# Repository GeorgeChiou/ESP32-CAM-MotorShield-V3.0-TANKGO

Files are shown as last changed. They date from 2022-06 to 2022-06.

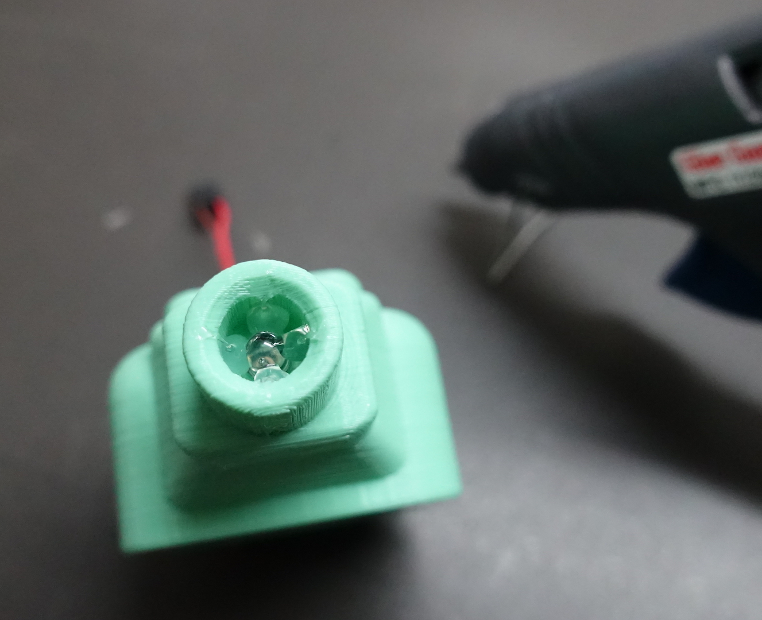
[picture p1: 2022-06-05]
Assembly Instruction/DSC00389.JPG

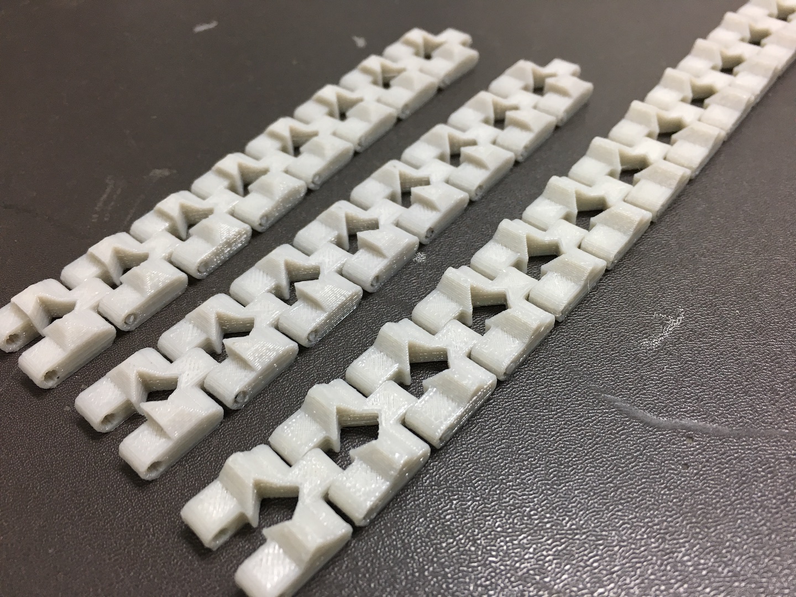
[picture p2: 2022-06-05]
Assembly Instruction/TANK_GO_3.JPG

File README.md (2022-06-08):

Key Features :<br>
Compact all-in-one design<br>
USB for Chargering<br>
Provide 4 GPIO ports to control up to 4 servo motors simultaneously<br>
I2C port for expansion of extra functions<br>
5V / 350mAh Lithium Ion Capacitor for power with nominal output of 10C<br>

Dimension is L55mm x W44mm x H23mm<br>

DC Motor x 2：2.5V ~ 6V , Avg. 1.2A , Max 2.0A<br>
Buzzer x 1 : SW3 ( Buzzer / P2 )<br>
I2C x 1 : ( P3 , P1 , 3.3V , GND )<br>
Ext. x 1 : ( P4 , P2 , VCC , GND )<br>
Upload Program x 1 : ( RX , TX , VCC , GND )

Power Consumption<br>
Idle Mode : 2mA<br>
Active Mode : 2.5A<br>
Operating Voltage : 3.9V ~ 5.1V<br>
Battery Voltage Indication : Red light below 3.9V, Green light above 4.2V<br>

電商販售連結 ICSHOP https://www.icshop.com.tw/product-page.php?28709<br>

LEGO Part :<br>
No.4666579 Axle Pin without Friction x 4pcs<br>
No.55982 Black Wheel 18mm D. x 14mm with Axle Hole x 4pcs<br>
No.43903 Technic Tread (Small) x 2pcs<br>
熱縮套管 heat shrink tube Φ2mm<div>ESP32-CAM Motor Shield - TANK GO ! Build Instruction 程式燒錄與組裝說明</div>
<div></div>

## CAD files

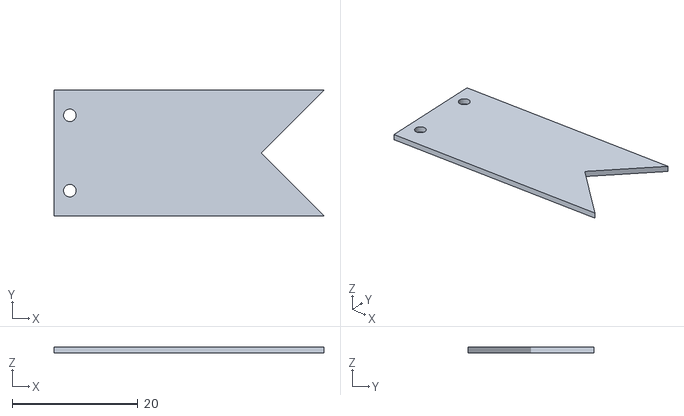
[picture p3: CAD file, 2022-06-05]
3DP STL BattleTower/TANK GO irBattleTower Flag.stl
43.0 x 20.0 x 1.00

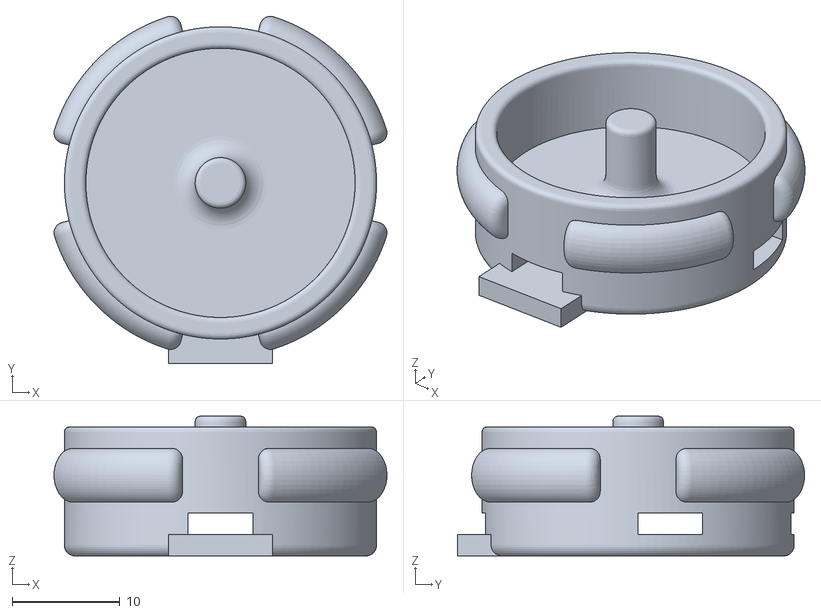
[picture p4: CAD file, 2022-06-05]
3DP STL TANKGO/GoodSmileDoll_IR_Cover.stl
30.9 x 32.3 x 13.0

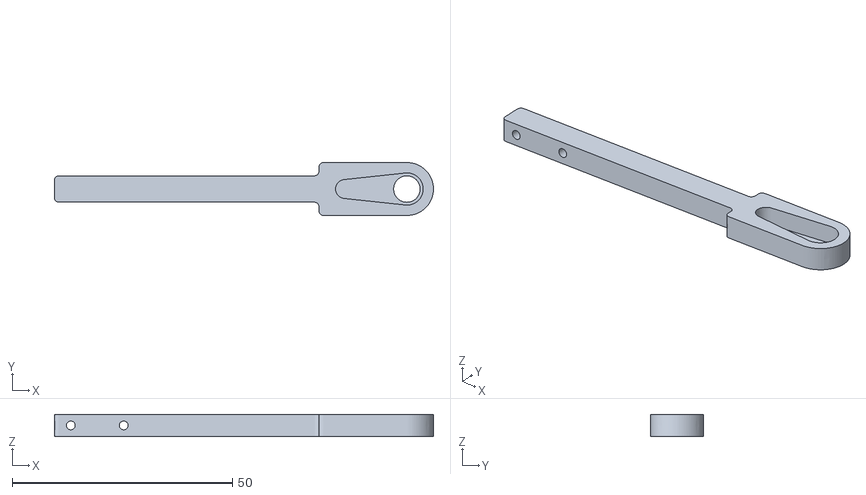
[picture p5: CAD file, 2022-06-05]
3DP STL BattleTower/TANK GO irBattleTower Stick.stl
86.0 x 12.0 x 5.00

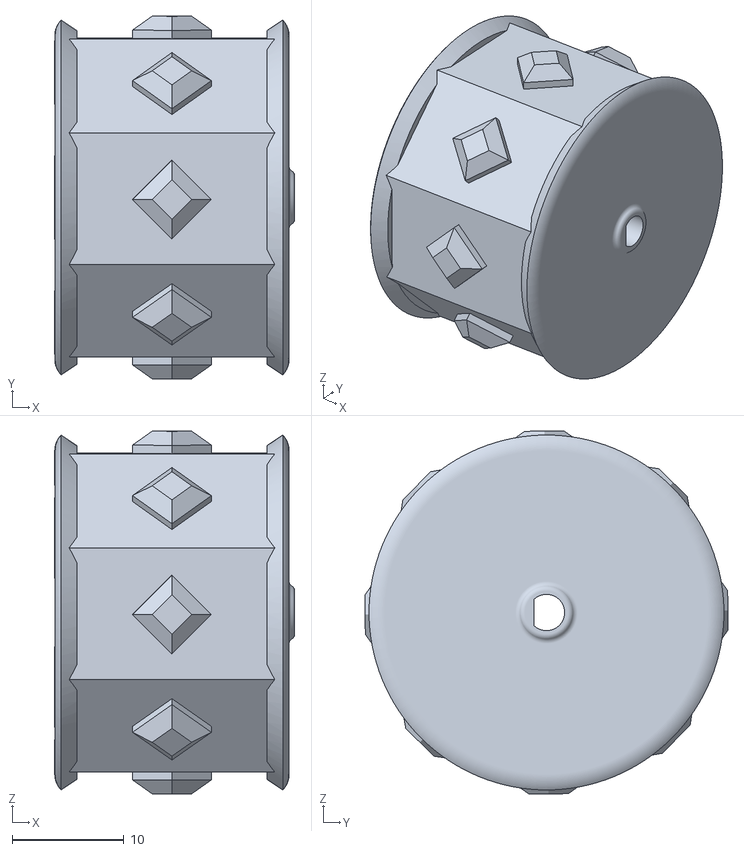
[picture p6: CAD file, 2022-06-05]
3DP STL TANKGO/Wheel_Master_2PCS.stl
21.5 x 32.5 x 32.5

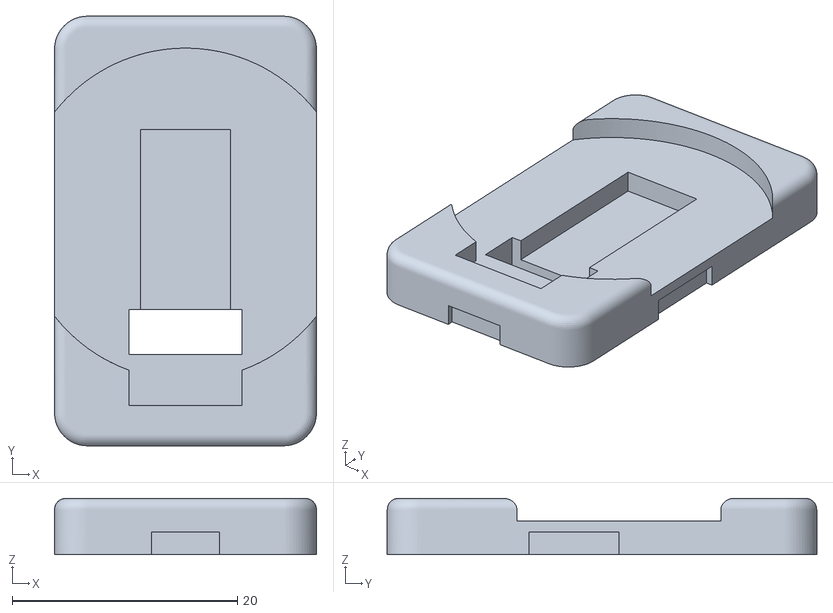
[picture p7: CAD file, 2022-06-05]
3DP STL BattleTower/GoodSmileDoll_Turret_Cover.stl
23.3 x 38.2 x 5.00

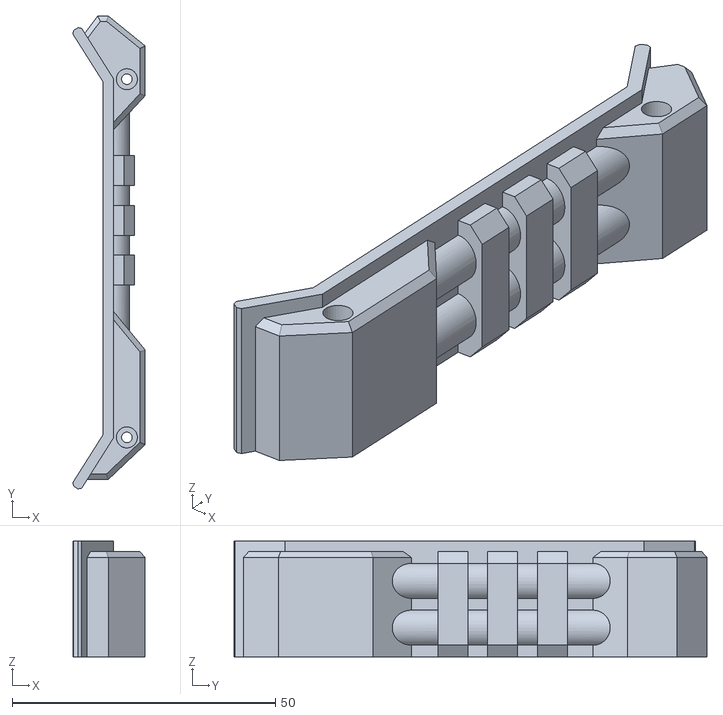
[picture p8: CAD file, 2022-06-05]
3DP STL TANKGO/Wheel_Armor_X_R.stl
13.7 x 89.8 x 22.0

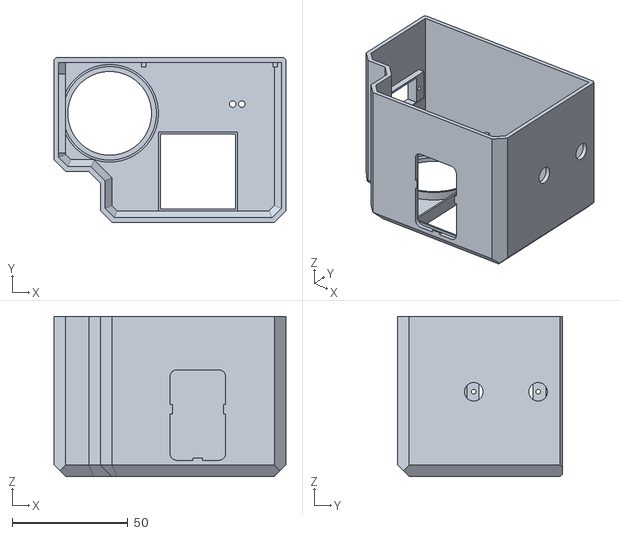
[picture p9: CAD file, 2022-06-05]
3DP STL BattleTower/TANK GO irBattleTower.stl
100.0 x 71.0 x 69.0

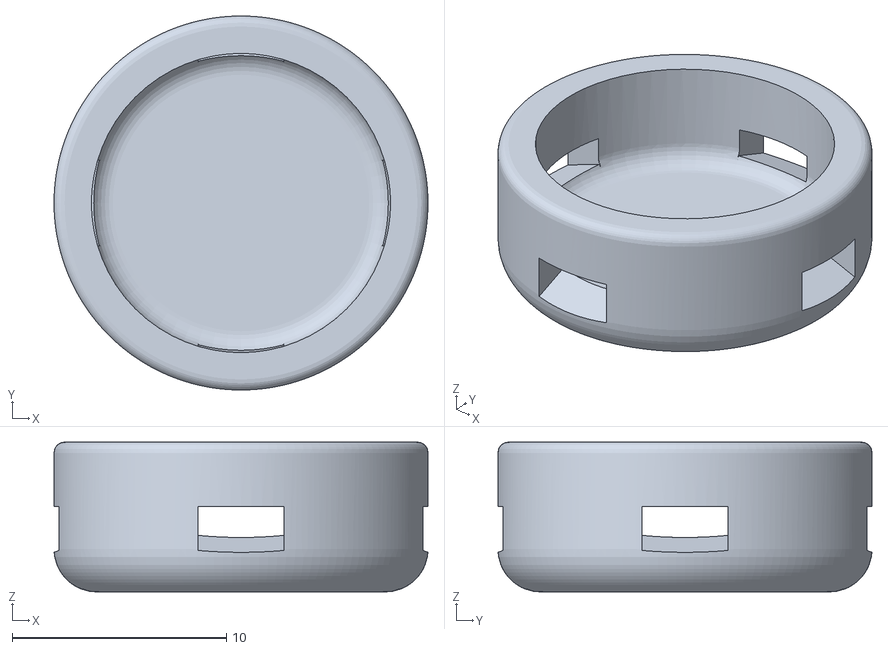
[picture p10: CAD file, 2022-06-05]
3DP STL TANKGO/IR_Cover.stl
17.5 x 17.5 x 7.00

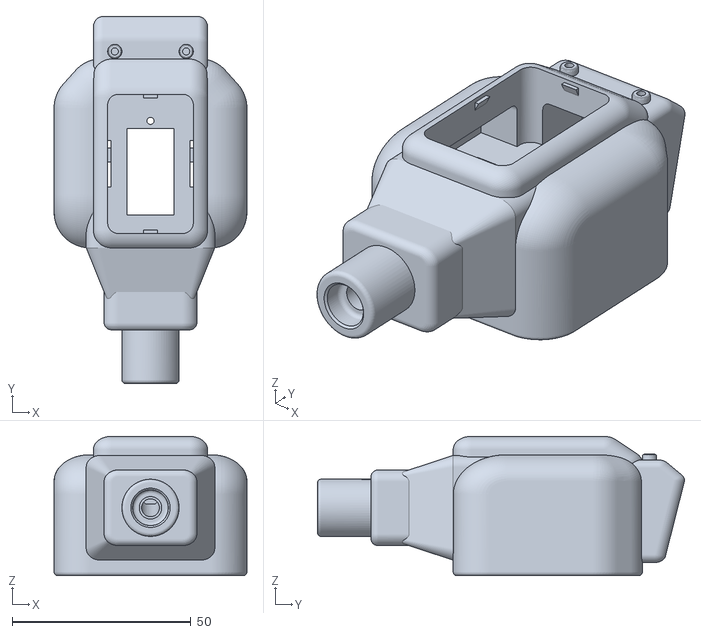
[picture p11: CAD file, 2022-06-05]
3DP STL TANKGO/Turret_MetalSlug.stl
54.0 x 102.8 x 39.0

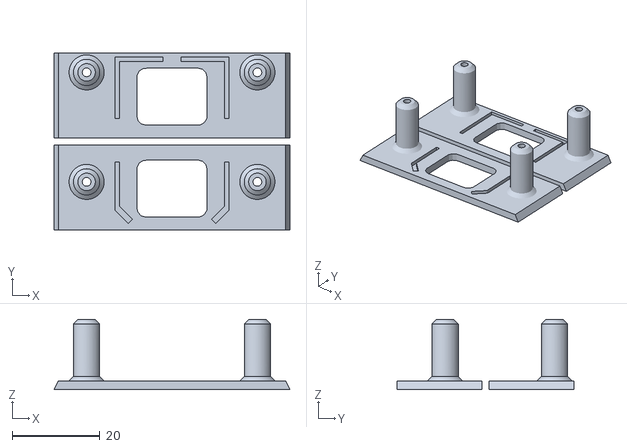
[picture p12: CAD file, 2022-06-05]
3DP STL BattleTower/ESP32CAM_MotorShield_Holding_Board.stl
53.9 x 40.5 x 16.0

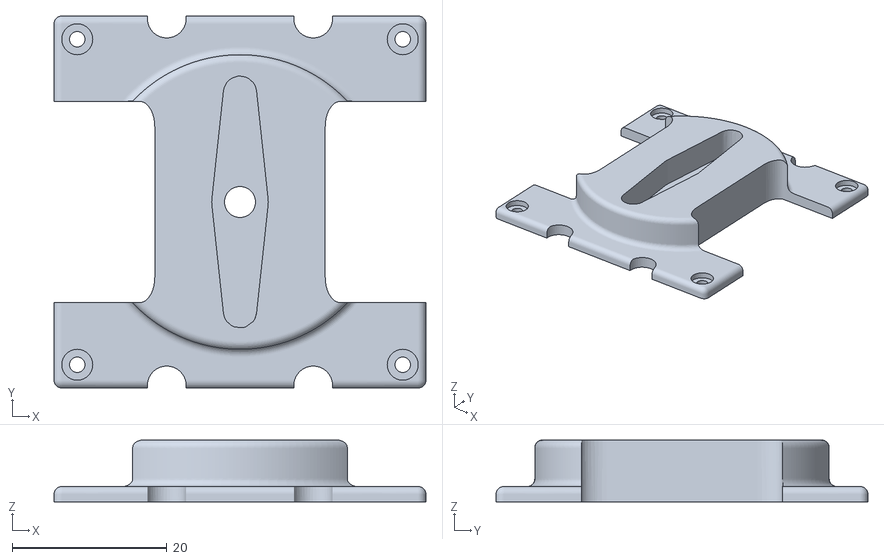
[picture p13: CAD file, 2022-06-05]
3DP STL TANKGO/Turret_Base.stl
48.0 x 48.0 x 8.00

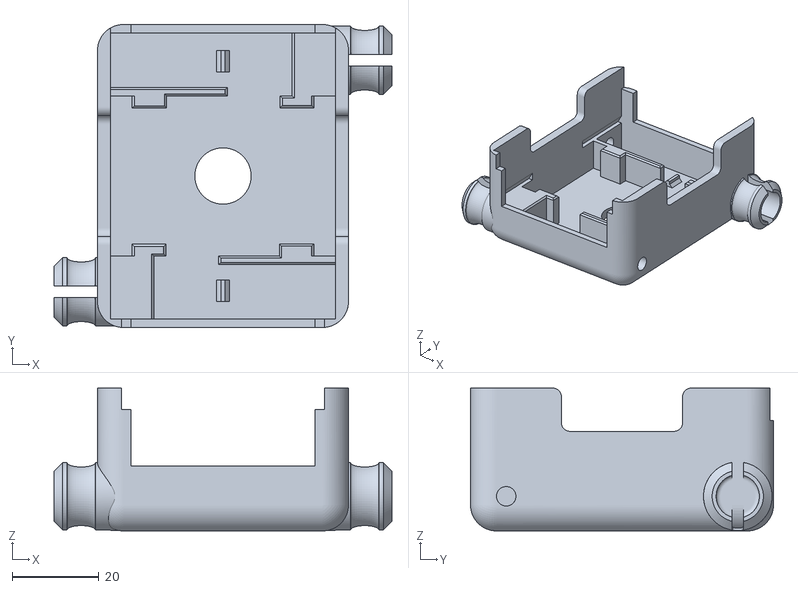
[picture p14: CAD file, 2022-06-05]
3DP STL TANKGO/Chassis.stl
78.1 x 70.0 x 33.0

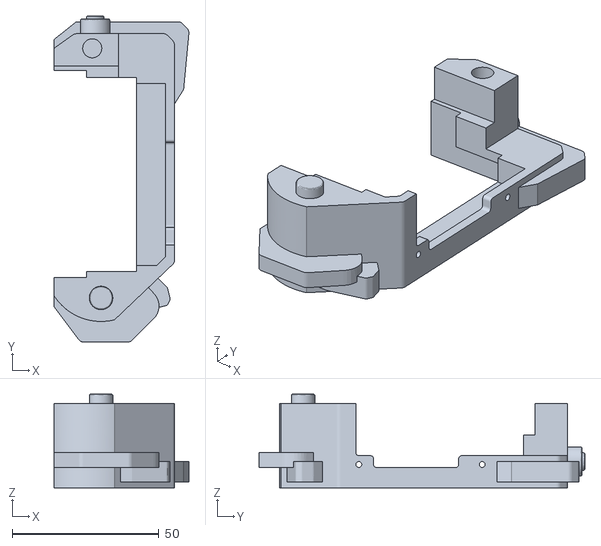
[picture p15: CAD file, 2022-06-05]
3DP STL TANKGO/ESP32CAM_MotorShield_Chassis_Armor_L.stl
45.9 x 111.0 x 32.0

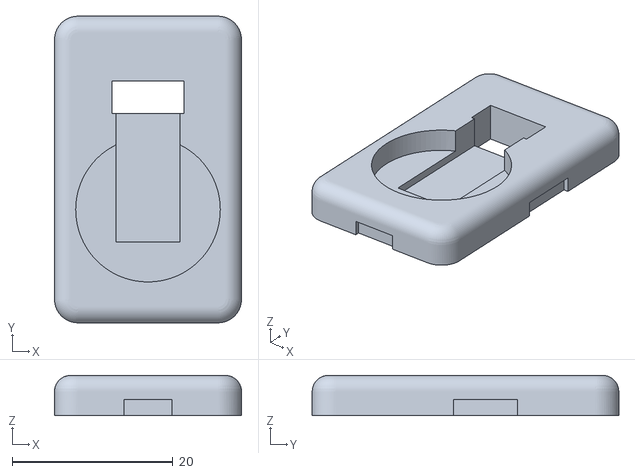
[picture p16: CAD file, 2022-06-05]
3DP STL TANKGO/IR_Turret_Cover.stl
23.3 x 38.2 x 5.00

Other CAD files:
3DP STL TANKGO/Wheel_Armor_X_L.stl
3DP STL TANKGO/ESP32CAM_MotorShield_Chassis_Armor_R.stl
3DP STL TANKGO/Turret_Sherman.stl
3DP STL TANKGO/Track_32PCS.stl
3DP STL TANKGO/Turret_Edelweiss.stl
3DP STL TANKGO/Turret_PanzerIV.stl
3DP STL TANKGO/Turret_TigerII.stl
3DP STL TANKGO/Turret_X.stl
3DP STL TANKGO/Wheel_Armor_A_L.stl
3DP STL TANKGO/Wheel_Armor_A_R.stl
3DP STL TANKGO/Wheel_Armor_S_2PCS.stl
3DP STL TANKGO/Wheel_Armor_T_2PCS.stl
3DP STL TANKGO/Wheel_Slave_2PCS.stl

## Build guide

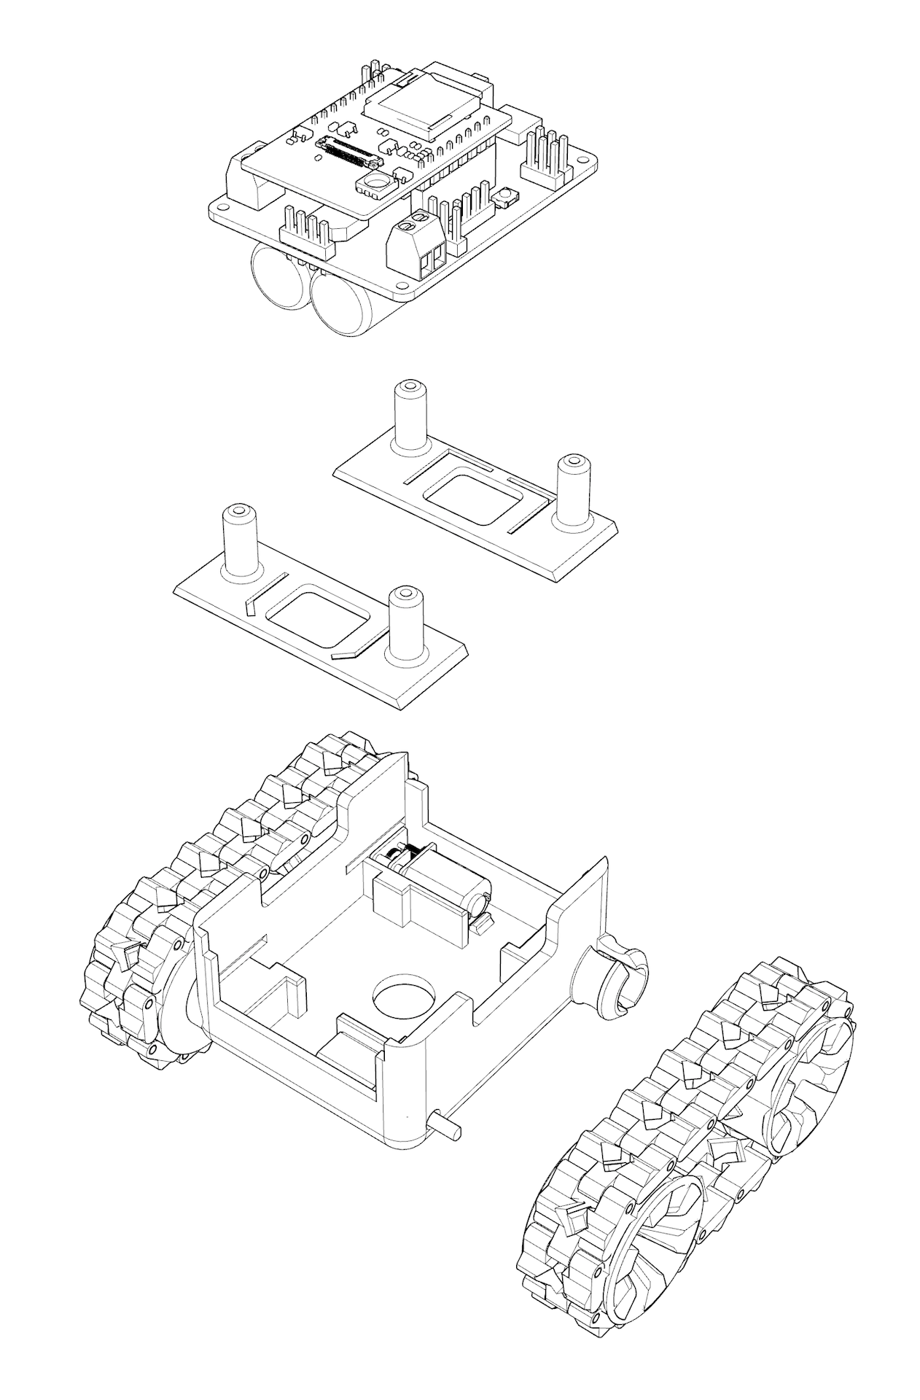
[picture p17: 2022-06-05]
Assembly Instruction/TANK_GO_4.png

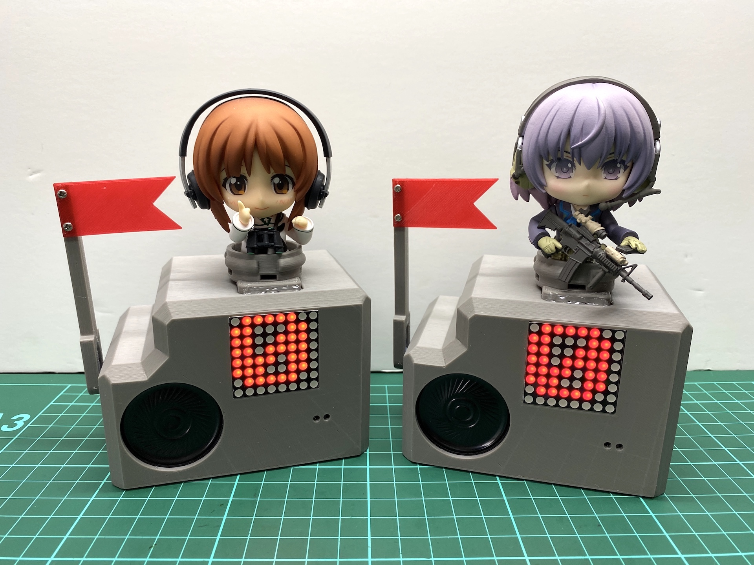
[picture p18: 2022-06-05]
Assembly Instruction/IMG_2081.JPG

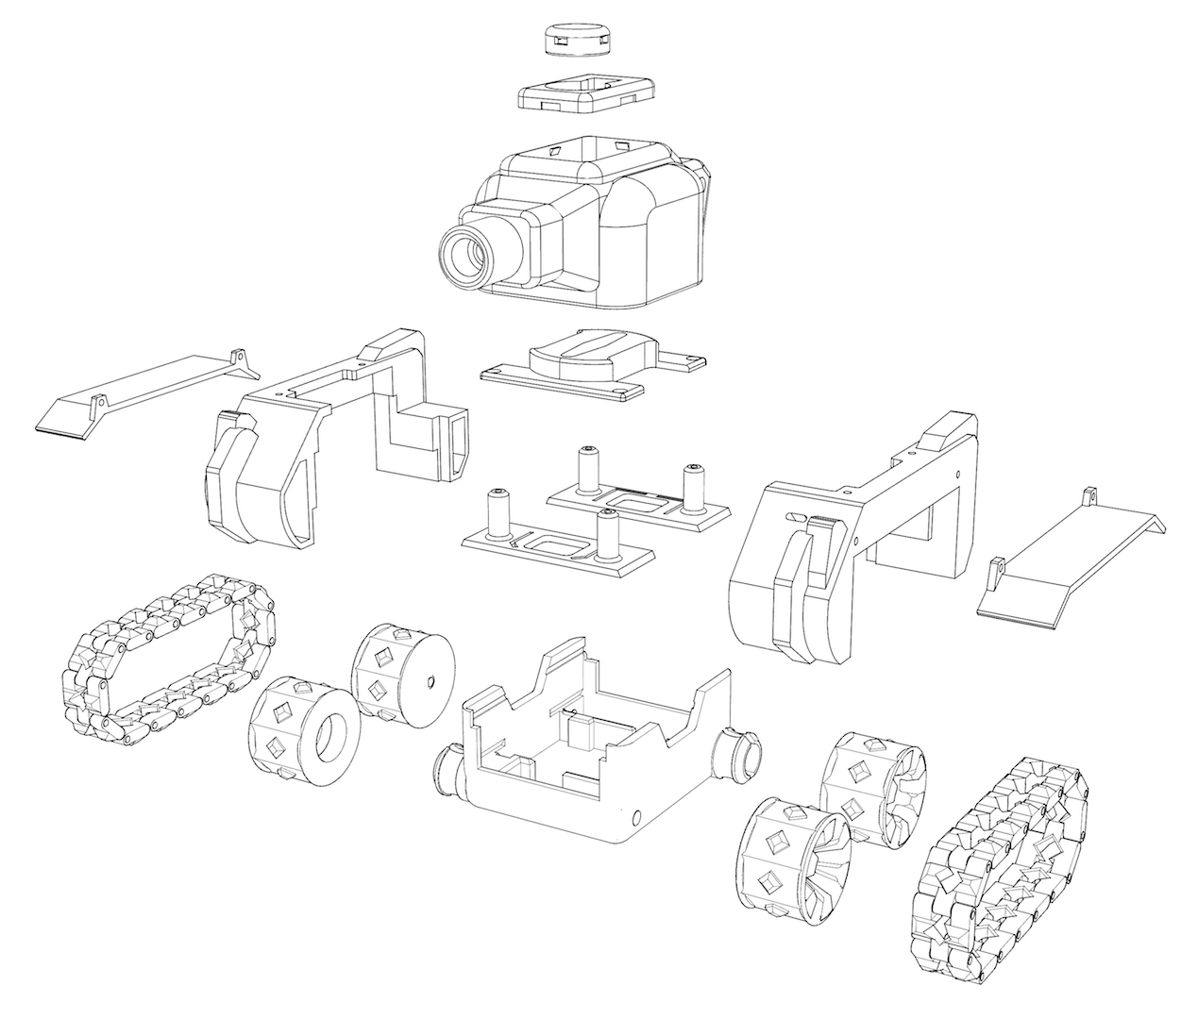
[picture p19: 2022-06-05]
Assembly Instruction/TANK_GO_5.png

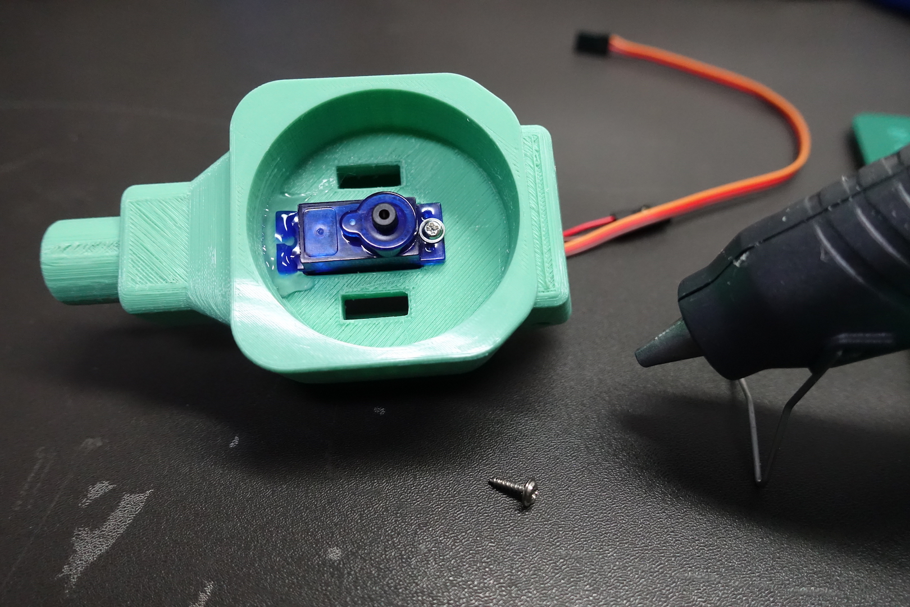
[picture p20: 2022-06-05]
Assembly Instruction/DSC00395.JPG

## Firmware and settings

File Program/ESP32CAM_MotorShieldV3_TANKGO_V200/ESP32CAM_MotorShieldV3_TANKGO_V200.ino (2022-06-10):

// 最後編輯 2021-12-25 by ShinWei Chiou
// 初版

// 最後編輯 2022-1-09 by ShinWei Chiou
// 修正 Analog Stick Motor value

// 最後編輯 2022-3-26 by ShinWei Chiou
// 增加 Damage_ValueZ >= 5;
// 被擊中到 5次 後暫停運作並且砲塔會左右搖擺，需按下 PS Button 解除再重新開始。

// 最後編輯 2022-6-10 by ShinWei Chiou
// Disable brownout detector

/*
  Board: ESP32 Wrover Module
  Upload Speed: 115200
  Flash Frequency: 80MHz
  Flash Mode: QIO
  Partition Scheme: Huge APP (3MB No OTA/1MB SPIFFS)

  ESP32-CAM Motor Shield V3.0
  MotorA = 15;
  MotorA = 14;
  MotorB = 13;
  MotorB = 12;
  Servo = 2;
  IR LED = 4;
  IR Receiver LED = 0;

  PS3 Controller Bluetooth Connect
  Pairing the PS3 Controller : SixaxisPairToolSetup-0.3.1.exe
  <https://github.com/jvpernis/esp32-ps3>

  DFRobot DFPlayer Mini : GND VCC TX
  https://github.com/DFRobot/DFRobotDFPlayerMini
  <https://www.dfrobot.com/product-1121.html>
*/

#include "soc/soc.h"
#include "soc/rtc_cntl_reg.h"

#include <Ps3Controller.h>
String ESP32_MAC_Address;

#include <HardwareSerial.h>
#include <DFRobotDFPlayerMini.h>
HardwareSerial mySerial(1);
DFRobotDFPlayerMini myDFPlayer;

int MP3_Play = 0;
int Volume_Value = 10;

// IR
#define IR_LED_Pin      4
#define IR_Receiver_Pin 0
int IR_Value = 0;
int Damage_Value = 0;

// Motor
#define MotorA14        14
#define MotorA15        15
#define MotorB12        12
#define MotorB13        13
#define MotorServo      2
#define MotorSChannel   1
int Turret_MaxMin_Lock = 0;


// Regarding the Datasheet of SG90 Servo, PWM Period is 20ms and Duty is 1->2ms
void servo_angle(int channel, int angle)
{
  int SERVO_RESOLUTION = 16;
  float range = (pow(2, SERVO_RESOLUTION) - 1) / 10;
  float minDuty = (pow(2, SERVO_RESOLUTION) - 1) / 40;

  uint32_t duty = (range) * (float)angle / 180.0 + minDuty;
  ledcWrite(channel, duty);
  delay(30);
}

// IR Send Code 38kHz
void IR_Send_Code()
{
  for (int i16t = 0; i16t < 16; i16t++)
  {
    for (int i37k = 0; i37k < 125; i37k++)
    {
      digitalWrite(IR_LED_Pin, HIGH);
      delayMicroseconds(12);
      digitalWrite(IR_LED_Pin, LOW);
      delayMicroseconds(12);
    }
    delay(2);
  }
}

void Move_Forward()
{
  digitalWrite(MotorA14, HIGH);
  digitalWrite(MotorA15, LOW);
  digitalWrite(MotorB12, HIGH);
  digitalWrite(MotorB13, LOW);
  delay(50);
}

void Move_Backward()
{
  digitalWrite(MotorA14, LOW);
  digitalWrite(MotorA15, HIGH);
  digitalWrite(MotorB12, LOW);
  digitalWrite(MotorB13, HIGH);
  delay(50);
}

void Move_TurnLeft()
{
  digitalWrite(MotorA14, LOW);
  digitalWrite(MotorA15, HIGH);
  digitalWrite(MotorB12, HIGH);
  digitalWrite(MotorB13, LOW);
  delay(50);
}

void Move_TurnRight()
{
  digitalWrite(MotorA14, HIGH);
  digitalWrite(MotorA15, LOW);
  digitalWrite(MotorB12, LOW);
  digitalWrite(MotorB13, HIGH);
  delay(50);
}

void Motor_Stop()
{
  digitalWrite(MotorA14, LOW);
  digitalWrite(MotorA15, LOW);
  digitalWrite(MotorB12, LOW);
  digitalWrite(MotorB13, LOW);
}

void Move_Fire()
{
  digitalWrite(MotorA14, LOW);
  digitalWrite(MotorA15, HIGH);
  digitalWrite(MotorB12, LOW);
  digitalWrite(MotorB13, HIGH);
  delay(100);
  digitalWrite(MotorA14, HIGH);
  digitalWrite(MotorA15, LOW);
  digitalWrite(MotorB12, HIGH);
  digitalWrite(MotorB13, LOW);
  delay(100);
  digitalWrite(MotorA14, HIGH);
  digitalWrite(MotorA15, HIGH);
  digitalWrite(MotorB12, HIGH);
  digitalWrite(MotorB13, HIGH);
  delay(100);
}

void Move_Damage()
{
  digitalWrite(MotorA14, LOW);
  digitalWrite(MotorA15, HIGH);
  digitalWrite(MotorB12, LOW);
  digitalWrite(MotorB13, HIGH);
  delay(200);
  digitalWrite(MotorA14, HIGH);
  digitalWrite(MotorA15, LOW);
  digitalWrite(MotorB12, HIGH);
  digitalWrite(MotorB13, LOW);
  delay(200);
  digitalWrite(MotorA14, HIGH);
  digitalWrite(MotorA15, HIGH);
  digitalWrite(MotorB12, HIGH);
  digitalWrite(MotorB13, HIGH);

  servo_angle(MotorSChannel, 120);
  delay(300);
  servo_angle(MotorSChannel, 60);
  delay(300);
  servo_angle(MotorSChannel, 120);
  delay(300);
  servo_angle(MotorSChannel, 90);
  delay(300);
  Turret_MaxMin_Lock = 0;
}


void setup()
{
  // Disable brownout detector
  WRITE_PERI_REG(RTC_CNTL_BROWN_OUT_REG, 0);

  // 設定 UART 通訊
  Serial.begin(9600);

  // 取得 ESP32-CAM MAC Address
  Ps3.begin();
  ESP32_MAC_Address = Ps3.getAddress();

  // 設定搖桿 LED 顯示
  Ps3.setPlayer(1);

  // 設定 Motor GPIO
  pinMode(MotorA14, OUTPUT); //MotorA
  pinMode(MotorA15, OUTPUT); //MotorA
  pinMode(MotorB12, OUTPUT); //MotorB
  pinMode(MotorB13, OUTPUT); //MotorB

  // 設定 IR GPIO
  pinMode(IR_LED_Pin, OUTPUT);
  pinMode(IR_Receiver_Pin, INPUT);

  // 設定 Servo Channel
  ledcSetup(MotorSChannel, 50, 16);
  ledcAttachPin(MotorServo, MotorSChannel);
  servo_angle(MotorSChannel, 90);

  // 顯示 ESP32-CAM MAC Address 等待連線！
  while (!Ps3.isConnected())
  {
    Serial.print("The ESP32's Bluetooth MAC address is: ");
    Serial.println(ESP32_MAC_Address);
    delay(1000);
  }

  // 將 Serial Port 設定給 DFplayer 使用
  mySerial.begin(9600, SERIAL_8N1, 3, 1); // begin(9600, SERIAL_8N1, RXD, TXD)
  myDFPlayer.begin(mySerial);
  myDFPlayer.volume(Volume_Value);
  myDFPlayer.playMp3Folder(13);
  MP3_Play = 1;
}


void loop()
{
  //--------------- IR Battle System ---------------
  if (digitalRead(IR_Receiver_Pin) == LOW)
  {
    IR_Value = pulseIn(IR_Receiver_Pin, LOW);
    if ( IR_Value >= 2700 && IR_Value <= 3400 )
    {
      Damage_Value++;
      myDFPlayer.playMp3Folder(2);
      Move_Damage();
    }
  }

  //--------------- Reset Damage Value ---------------
  if ( Ps3.data.button.ps && Damage_Value >= 5 )
  {
    Damage_Value = 0;

    myDFPlayer.playMp3Folder(13);
    MP3_Play = 1;
    delay(300);
  }


  //--------------------- Damage ---------------------
  if ( Damage_Value >= 5 )
  {
    servo_angle(MotorSChannel, 110);
    delay(200);
    servo_angle(MotorSChannel, 70);
    delay(200);
    servo_angle(MotorSChannel, 110);
    delay(200);
    servo_angle(MotorSChannel, 90);
    delay(300);
  }
  else
  {


    //--------------- Digital D-pad button --------------
    if ( Ps3.data.button.up )
    {
      Move_Forward();
    }
    else if ( Ps3.data.button.down )
    {
      Move_Backward();
    }
    else if ( Ps3.data.button.left )
    {
      Move_TurnLeft();
    }
    else if ( Ps3.data.button.right )
    {
      Move_TurnRight();
    }

    //--------------- Digital Trigger button ------------
    if ( Ps3.data.button.l1 )
    {
      digitalWrite(MotorA14, HIGH);
      digitalWrite(MotorA15, LOW);
      delay(50);
    }
    else if ( Ps3.data.button.l2 )
    {
      digitalWrite(MotorA14, LOW);
      digitalWrite(MotorA15, HIGH);
      delay(50);
    }

    if ( Ps3.data.button.r1 )
    {
      digitalWrite(MotorB12, HIGH);
      digitalWrite(MotorB13, LOW);
      delay(50);
    }
    else if ( Ps3.data.button.r2 )
    {
      digitalWrite(MotorB12, LOW);
      digitalWrite(MotorB13, HIGH);
      delay(50);
    }

    //--------------- Analog Stick Motor value ------------
    if (abs(Ps3.data.analog.stick.lx) < 30 && abs(Ps3.data.analog.stick.ly) < 30)
    {
      Motor_Stop() ;
    }
    else if (abs(Ps3.data.analog.stick.lx) > abs(Ps3.data.analog.stick.ly))
    {
      if (Ps3.data.analog.stick.lx > 20)
      {
        Move_TurnRight();
      }
      else
      {
        Move_TurnLeft();
      }
    }
    else
    {
      if (Ps3.data.analog.stick.ly < -20)
      {
        Move_Forward();
      }
      else
      {
        Move_Backward();
      }
    }

    //--- Digital cross/square/triangle/circle button ---
    if ( Ps3.data.button.triangle )
    {
      Turret_MaxMin_Lock = 90;
      servo_angle(MotorSChannel, Turret_MaxMin_Lock);
    }
    if ( Ps3.data.button.circle )
    {
      if (Turret_MaxMin_Lock == 0)
      {
        Turret_MaxMin_Lock = 90;
      }
      else if (Turret_MaxMin_Lock >= 20)
      {
        Turret_MaxMin_Lock = Turret_MaxMin_Lock - 2;
      }
      else
      {
        Turret_MaxMin_Lock = 20;
      }
      servo_angle(MotorSChannel, Turret_MaxMin_Lock);
    }
    if ( Ps3.data.button.square )
    {
      if (Turret_MaxMin_Lock == 0)
      {
        Turret_MaxMin_Lock = 90;
      }
      else if (Turret_MaxMin_Lock <= 160)
      {
        Turret_MaxMin_Lock = Turret_MaxMin_Lock + 2;
      }
      else
      {
        Turret_MaxMin_Lock = 160;
      }
      servo_angle(MotorSChannel, Turret_MaxMin_Lock);
    }
    if ( Ps3.data.button.cross )
    {
      myDFPlayer.playMp3Folder(1);
      IR_Send_Code();
      Move_Fire();
      delay (800);
      myDFPlayer.playMp3Folder(3);
    }

    //--------------- Analog Stick Turret value ------------
    if ( abs(Ps3.data.analog.stick.rx) > 2 )
    {
      servo_angle(MotorSChannel, 90 - (Ps3.data.analog.stick.rx) / 2);
      Turret_MaxMin_Lock = 0;
    }
    else
    {
      if (Turret_MaxMin_Lock == 0)
      {
        servo_angle(MotorSChannel, 90);
      }
    }


  }


  //---------- Digital select/start button events ---------
  if ( Ps3.data.button.start )
  {
    if (MP3_Play == 0)
    {
      myDFPlayer.playMp3Folder(13);
      MP3_Play = 1;
      delay(300);
    }
    else
    {
      MP3_Play = 0;
      myDFPlayer.stop();
      delay(300);
    }
  }
  if ( Ps3.data.button.select )
  {
    if (Volume_Value <= 25)
    {
      Volume_Value = Volume_Value + 5;
      myDFPlayer.volume(Volume_Value);
      delay(300);
    }
    else
    {
      Volume_Value = 10;
      myDFPlayer.volume(Volume_Value);
      delay(300);
    }
  }
}

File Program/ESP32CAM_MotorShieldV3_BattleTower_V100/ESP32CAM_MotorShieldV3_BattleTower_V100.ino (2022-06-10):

// 最後編輯 2022-3-20 by ShinWei Chiou
// 初版

// 最後編輯 2022-6-10 by ShinWei Chiou
// Disable brownout detector

/*
  Board: ESP32 Wrover Module
  Upload Speed: 115200
  Flash Frequency: 80MHz
  Flash Mode: QIO
  Partition Scheme: Huge APP (3MB No OTA/1MB SPIFFS)

  ESP32-CAM Motor Shield V3.0
  MAX7219 CLK : P14 , CS : P13 , DIN : P12
  Servo : P2
  IR Receiver : P0

  DFRobot DFPlayer Mini : GND VCC TX
  https://github.com/DFRobot/DFRobotDFPlayerMini
  <https://www.dfrobot.com/product-1121.html>
*/

#include "soc/soc.h"
#include "soc/rtc_cntl_reg.h"

#include <HardwareSerial.h>
#include <DFRobotDFPlayerMini.h>
HardwareSerial mySerial(1);
DFRobotDFPlayerMini myDFPlayer;

// IR
#define IR_Receiver_Pin 0
int IR_Value = 0;

// Servo
#define MotorServo      2
#define MotorSChannel   1

// MAX7219 8x8 Dot Matrices
#define MAX7219_CLK_Pin  14
#define MAX7219_CS_Pin   13
#define MAX7219_DIN_Pin  12

// MAX7219 address map
#define MAX7219_DECODE_REG      (0x09)
#define MAX7219_INTENSITY_REG   (0x0A)
#define MAX7219_SCANLIMIT_REG   (0x0B)
#define MAX7219_SHUTDOWN_REG    (0X0C)
#define MAX7219_DISPLAYTEST_REG (0x0F)
#define MAX7219_DIGIT_REG(pos)  ((pos) + 1)
#define MAX7219_COLUMN_REG(pos) MAX7219_DIGIT_REG(pos)

// shutdown mode
#define MAX7219_OFF             (0x0)
#define MAX7219_ON              (0x1)

// number of columns of the display matrx
#define NUM_OF_COLUMNS  (8)

// for each character bitmap, it consumes bytes
#define BYTE_PER_MAP    (8)

unsigned int char_index = 5;
unsigned int rsset_index = 0;

// matrix pattern
const byte char_pattern[] =
{
  0x00, 0x3E, 0x67, 0x6F, 0x7B, 0x73, 0x63, 0x3E, // 0
  0x00, 0x3F, 0x0C, 0x0C, 0x0C, 0x0C, 0x0E, 0x0C, // 1
  0x00, 0x3F, 0x33, 0x06, 0x1C, 0x30, 0x33, 0x1E, // 2
  0x00, 0x1E, 0x33, 0x30, 0x1C, 0x30, 0x33, 0x1E, // 3
  0x00, 0x78, 0x30, 0x7F, 0x33, 0x36, 0x3C, 0x38, // 4

  0x00, 0x1E, 0x33, 0x30, 0x30, 0x1F, 0x03, 0x3F, // 5
  0x00, 0x1E, 0x33, 0x33, 0x1F, 0x03, 0x06, 0x1C, // 6
  0x00, 0x0C, 0x0C, 0x0C, 0x18, 0x30, 0x33, 0x3F, // 7
  0x00, 0x1E, 0x33, 0x33, 0x1E, 0x33, 0x33, 0x1E, // 8
  0x00, 0x0E, 0x18, 0x30, 0x3E, 0x33, 0x33, 0x1E, // 9

  //  0x00, 0x33, 0x33, 0x3F, 0x33, 0x33, 0x1E, 0x0C, // A
  //  0x00, 0x3F, 0x66, 0x66, 0x3E, 0x66, 0x66, 0x3F, // B
  //  0x00, 0x3C, 0x66, 0x03, 0x03, 0x03, 0x66, 0x3C, // C
  //  0x00, 0x1F, 0x36, 0x66, 0x66, 0x66, 0x36, 0x1F, // D
  //  0x00, 0x7F, 0x46, 0x16, 0x1E, 0x16, 0x46, 0x7F, // E
  //  0x00, 0x0F, 0x06, 0x16, 0x1E, 0x16, 0x46, 0x7F, // F

  0x00, 0x63, 0x36, 0x1C, 0x1C, 0x36, 0x63, 0x63, // X
  0x00, 0x1C, 0x36, 0x63, 0x63, 0x63, 0x36, 0x1C, // O

  0xFF, 0xFF, 0xFF, 0xFF, 0xFF, 0xFF, 0xFF, 0xFF, // Full
  0x00, 0x00, 0x00, 0x00, 0x00, 0x00, 0x00, 0x00  // space
};

#define DISPLAY_STR_LENGTH  (sizeof(char_pattern) / BYTE_PER_MAP)

void Set_MAX7219_register(byte address, byte value)
{
  digitalWrite(MAX7219_CS_Pin, LOW);
  shiftOut(MAX7219_DIN_Pin, MAX7219_CLK_Pin, MSBFIRST, address);
  shiftOut(MAX7219_DIN_Pin, MAX7219_CLK_Pin, MSBFIRST, value);
  digitalWrite(MAX7219_CS_Pin, HIGH);
}

void Clear_MAX7219_matrix()
{
  // clear the dot matrix
  for (int i = 0; i < NUM_OF_COLUMNS; i++)
  {
    Set_MAX7219_register(MAX7219_COLUMN_REG(i), B00000000);
  }
}

void Initialize_MAX2719()
{
  // disable test mode.
  Set_MAX7219_register(MAX7219_DISPLAYTEST_REG, MAX7219_OFF);

  // set medium intensity.
  Set_MAX7219_register(MAX7219_INTENSITY_REG, 0x1);

  // turn off display.
  Set_MAX7219_register(MAX7219_SHUTDOWN_REG, MAX7219_OFF);

  // drive 8 digits.
  Set_MAX7219_register(MAX7219_SCANLIMIT_REG, 7);

  // no decode mode for all positions.
  Set_MAX7219_register(MAX7219_DECODE_REG, B00000000);

  // clear matrix display
  Clear_MAX7219_matrix();
}

void Display_MAX2719()
{
  // turn off display first
  Set_MAX7219_register(MAX7219_SHUTDOWN_REG, MAX7219_OFF);

  // display one bitmap
  for (int i = 0; i < BYTE_PER_MAP; i++)
  {
    // starting from column
    Set_MAX7219_register(MAX7219_COLUMN_REG(i), char_pattern[char_index * BYTE_PER_MAP + i]);
  }

  // turn on display
  Set_MAX7219_register(MAX7219_SHUTDOWN_REG, MAX7219_ON);
}

// Regarding the Datasheet of SG90 Servo, PWM Period is 20ms and Duty is 1->2ms
void servo_angle(int channel, int angle)
{
  int SERVO_RESOLUTION = 16;
  float range = (pow(2, SERVO_RESOLUTION) - 1) / 10;
  float minDuty = (pow(2, SERVO_RESOLUTION) - 1) / 40;

  uint32_t duty = (range) * (float)angle / 180.0 + minDuty;
  ledcWrite(channel, duty);
  delay(30);
}

/*------------------------------------------------------------*/
void setup()
{
  // Disable brownout detector
  WRITE_PERI_REG(RTC_CNTL_BROWN_OUT_REG, 0);

  // Initialize serial communications at 9600 bps:
  Serial.begin(9600);

  // MAX7219 PIN Set
  pinMode(MAX7219_CLK_Pin, OUTPUT);
  pinMode(MAX7219_CS_Pin, OUTPUT);
  pinMode(MAX7219_DIN_Pin, OUTPUT);

  // IR PIN Set
  pinMode(IR_Receiver_Pin, INPUT);

  // 設定 Servo Channel
  ledcSetup(MotorSChannel, 50, 16);
  ledcAttachPin(MotorServo, MotorSChannel);
  servo_angle(MotorSChannel, 90);

  // Initialize MAX2719 states
  Initialize_MAX2719();
  Display_MAX2719();

  // 將 Serial Port 設定給 DFplayer 使用
  mySerial.begin(9600, SERIAL_8N1, 3, 1); // begin(9600, SERIAL_8N1, RXD, TXD)
  myDFPlayer.begin(mySerial);
  myDFPlayer.volume(30);
  myDFPlayer.playMp3Folder(15);
}


/*------------------------------------------------------------*/
void loop()
{
  //--------------- IR Battle System ---------------
  if (digitalRead(IR_Receiver_Pin) == LOW)
  {
    IR_Value = pulseIn(IR_Receiver_Pin, LOW);

    if ( IR_Value >= 2700 && IR_Value <= 3400 )
    {
      if (char_index >= 10)
      {
        rsset_index++;

        if (rsset_index >= 4)
        {
          char_index = 6;
          rsset_index = 0;
          Display_MAX2719();
        }
      }
      else if (char_index >= 2)
      {
        char_index--;
        Display_MAX2719();

        myDFPlayer.playMp3Folder(2);

        servo_angle(MotorSChannel, 110);
        delay (500);
        servo_angle(MotorSChannel, 70);
        delay (500);
        servo_angle(MotorSChannel, 90);
      }
      else
      {
        char_index = 10;
        Display_MAX2719();

        myDFPlayer.playMp3Folder(1);

        servo_angle(MotorSChannel, 170);
        delay (5000);
      }
    }
  }
}
